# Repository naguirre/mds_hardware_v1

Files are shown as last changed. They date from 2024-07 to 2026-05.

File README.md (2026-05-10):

# mds-hardware

KiCad sources and fabrication outputs for a small network audio player board built around an Allwinner F1C200s SoC, an ESP32-C3 for Wi-Fi, NAND flash storage, an EA3036 power management IC, and an audio DAC daughter board.

The repository contains two KiCad projects:
- [network_player/](network_player/) — the main board
- [dac/](dac/) — the audio DAC daughter board

## Versions

| Version | Date | Status | Schematic | PCB | Gerbers |
|---|---|---|---|-----|---|
| v1 | 2024-01-15 | Sent to JLCPCB, had routing issues | [PDF](docs/v1/schematic.pdf) | [PDF](docs/v1/pcb.pdf) | [ZIP](docs/v1/gerbers.zip) |
| v1.1 | 2024-06-02 | Sent to JLCPCB, fixes routing issues of v1 | [PDF](docs/v1.1/schematic.pdf) | [PDF](docs/v1.1/pcb.pdf) | [ZIP](docs/v1.1/gerbers.zip) |
| v2 | 2024-10-17 | Full redesign on Allwinner T113-s3, never produced | [PDF](docs/v2/schematic.pdf) | [PDF](docs/v2/pcb.pdf) | [ZIP](docs/v2/gerbers.zip) |

References on GitHub: v1 is at commit [`c1560a5`](../../commit/c1560a5), v1.1 is the [`v1.1`](../../tree/v1.1) tag, v2 lives on the [`network_player_v2`](../../tree/network_player_v2) branch. The [`v1_jlcpcb`](../../tree/v1_jlcpcb) tag points to the JLCPCB return files for v1.

## Latest produced version: v1.1

v1.1 is the version that was actually fabricated and assembled by JLCPCB. Compared to v1, it brings the following changes (see commit [`47ae173`](../../commit/47ae173)):

- Removed the discrete transistors used for ESP32 boot/reset, driven directly from F1C200s GPIOs instead
- EA3036 enable pin tied to 3.3 V
- Added a RST button that pulls the MISO line to ground to disable booting from flash
- ESP32 moved to SPI1; SPI0 is now shared between the NAND flash and the RPi connector

### Schematic

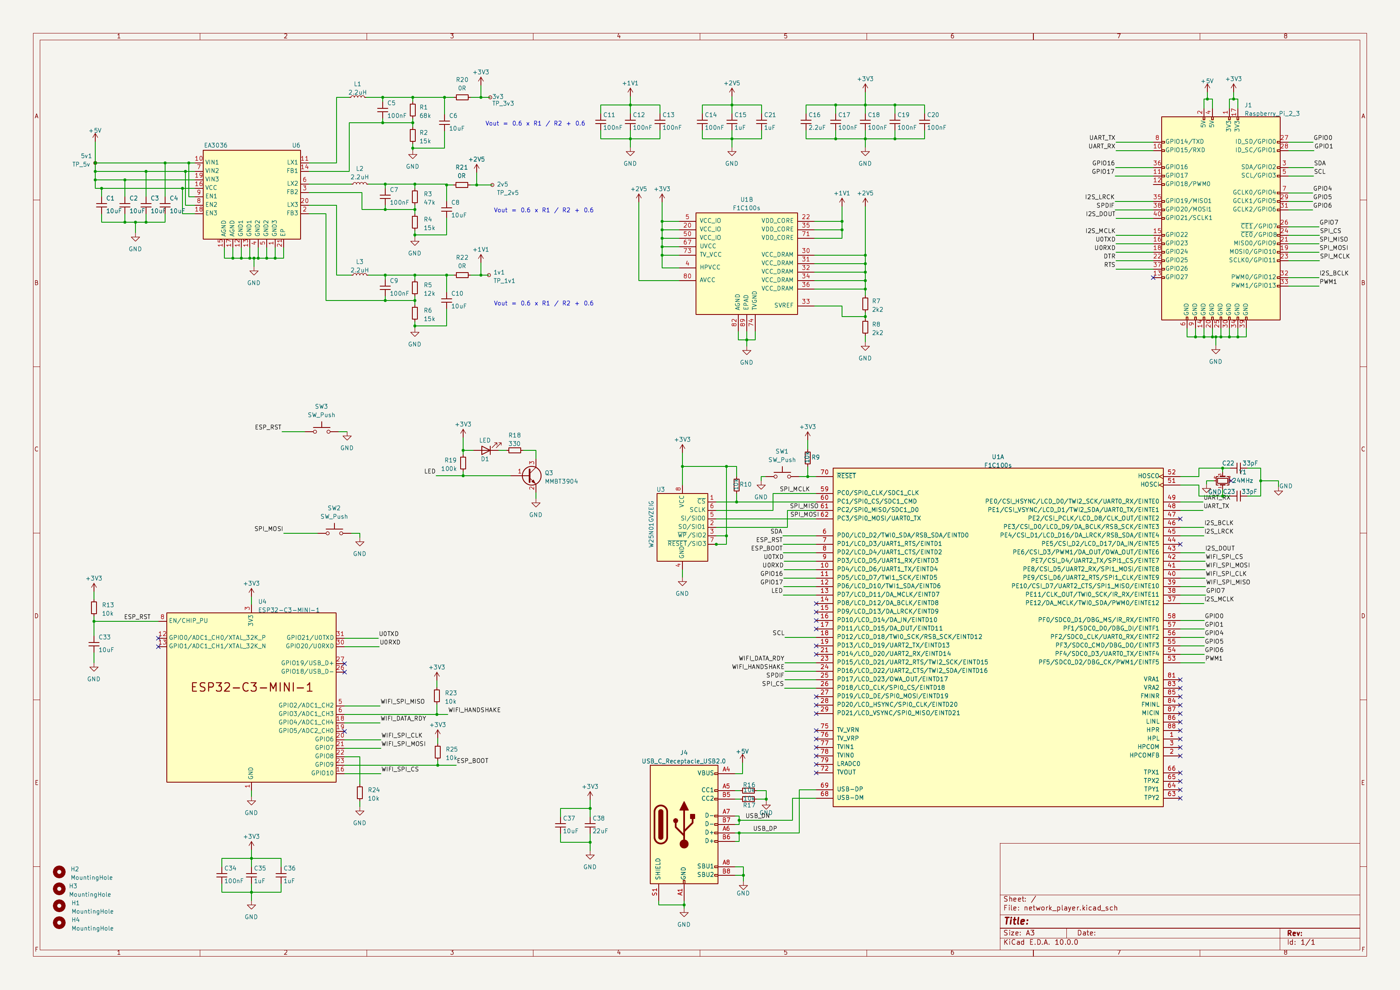
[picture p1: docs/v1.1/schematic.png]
v1.1 schematic


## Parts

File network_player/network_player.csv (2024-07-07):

Comment | Designator | Footprint | LCSC
TP_1v1 | Connector:TestPoint_Small | 1v1
TP_2v5 | Connector:TestPoint_Small | 2v5
TP_3v3 | Connector:TestPoint_Small | 3v3
TP_5v | Connector:TestPoint_Small | 5v1
10uF | Device:C_Small | C1, C2, C3, C4, C6, C8, C10, C33, C37 | C15525
100nF | Device:C_Small | C5, C7, C9, C11, C12, C13, C14, C17, C18, C19, C20, C34 | C307331
1uF | Device:C_Small | C15, C21, C35, C36 | C52923
2.2uF | Device:C_Small | C16 | C12530
33pF | Device:C_Small | C22, C23 | C1562
22uF | Device:C_Small | C38 | C59461
LED | Device:LED | D1 | C2290
MountingHole | Mechanical:MountingHole | H1, H2, H3, H4
Raspberry_Pi_2_3 | Connector:Raspberry_Pi_2_3 | J1
USB_C_Receptacle_USB2.0 | Connector:USB_C_Receptacle_USB2.0 | J4 | C963370
2.2uH | Device:L_Small | L1, L2, L3 | C1043
MMBT3904 | Transistor_BJT:MMBT3904 | Q3 | C20526
68k | Device:R_Small | R1 | C36871
15k | Device:R_Small | R2, R4, R6 | C25756
47k | Device:R_Small | R3 | C25792
12k | Device:R_Small | R5 | C25752
2k2 | Device:R_Small | R7, R8 | C25879
10k | Device:R_Small | R9, R10, R13, R16, R17, R23, R24, R25 | C25744
330 | Device:R_Small | R18 | C25104
100k | Device:R_Small | R19 | C25741
0R | Device:R_Small | R20, R21, R22 | C17168
SW_Push | Switch:SW_Push | SW1, SW2, SW3 | C318884
F1C100s | f1c100s:F1C100s | U1 | C2879851
W25N01GVZEIG | Memory_Flash:MX25R3235FZNxx0 | U3 | C88868
ESP32-C3-MINI-1 | Espressif:ESP32-C3-MINI-1 | U4 | C2838502
EA3036 | EA3036:EA3036 | U6 | C570857
24MHz | Device:Crystal_GND24_Small | Y1 | C15643

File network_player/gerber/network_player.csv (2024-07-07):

Comment | Designator | Footprint | LCSC
TP_1v1 | 1v1 | TestPoint:TestPoint_Pad_D1.0mm
TP_2v5 | 2v5 | TestPoint:TestPoint_Pad_D1.0mm
TP_3v3 | 3v3 | TestPoint:TestPoint_Pad_D1.0mm
TP_5v | 5v1 | TestPoint:TestPoint_Pad_D1.0mm
10uF | C1,C2,C3,C4,C6,C8,C10,C33,C37 | Capacitor_SMD:C_0402_1005Metric | C15525
1uF | C15,C21,C35,C36 | Capacitor_SMD:C_0402_1005Metric | C52923
2.2uF | C16 | Capacitor_SMD:C_0402_1005Metric | C12530
33pF | C22,C23 | Capacitor_SMD:C_0402_1005Metric | C1562
22uF | C38 | Capacitor_SMD:C_0805_2012Metric | C59461
100nF | C5,C7,C9,C11,C12,C13,C14,C17,C18,C19,C20,C34 | Capacitor_SMD:C_0402_1005Metric | C307331
LED | D1 | LED_SMD:LED_0603_1608Metric
MountingHole | H1,H2,H3,H4 | MountingHole:MountingHole_2.7mm_M2.5
Raspberry_Pi_2_3 | J1 | Connector_PinHeader_2.54mm:PinHeader_2x20_P2.54mm_Vertical
USB_C_Receptacle_USB2.0 | J4 | Connector_USB:USB_C_Receptacle_GT-USB-7010 | C963370
2.2uH | L1,L2,L3 | Inductor_SMD:L_0805_2012Metric | C1043
BC817 | Q1,Q2 | Package_TO_SOT_SMD:SOT-23 | C2150
MMBT3904 | Q3 | Package_TO_SOT_SMD:SOT-23 | C20526
68k | R1 | Resistor_SMD:R_0402_1005Metric | C36871
0R | R11,R12,R20,R21,R22 | Resistor_SMD:R_0402_1005Metric | C17168
330 | R18 | Resistor_SMD:R_0402_1005Metric | C25104
100k | R19 | Resistor_SMD:R_0402_1005Metric | C25741
15k | R2,R4,R6 | Resistor_SMD:R_0402_1005Metric | C25756
47k | R3 | Resistor_SMD:R_0402_1005Metric | C25792
12k | R5 | Resistor_SMD:R_0402_1005Metric | C25752
2k2 | R7,R8 | Resistor_SMD:R_0402_1005Metric | C25879
10k | R9,R10,R13,R14,R15,R16,R17 | Resistor_SMD:R_0402_1005Metric | C25744
SW_Push | SW1,SW2,SW3 | Button_Switch_SMD:SW_Push_1P1T_XKB_TS-1187A | C318884
F1C100s | U1 | Package_DFN_QFN:QFN-88_EP_10x10_Pitch0.4mm | C2879851
W25N01GVZEIG | U3 | Package_SON:WSON-8-1EP_8x6mm_P1.27mm_EP3.4x4.3mm | C88868
ESP32-C3-MINI-1 | U4 | espressif:ESP32-C3-MINI-1 | C2838502
EA3036 | U6 | Package_DFN_QFN:QFN-20-1EP_3x3mm_P0.4mm_EP1.65x1.65mm | C570857
24MHz | Y1 | Crystal:Crystal_SMD_SeikoEpson_TSX3225-4Pin_3.2x2.5mm | C15643

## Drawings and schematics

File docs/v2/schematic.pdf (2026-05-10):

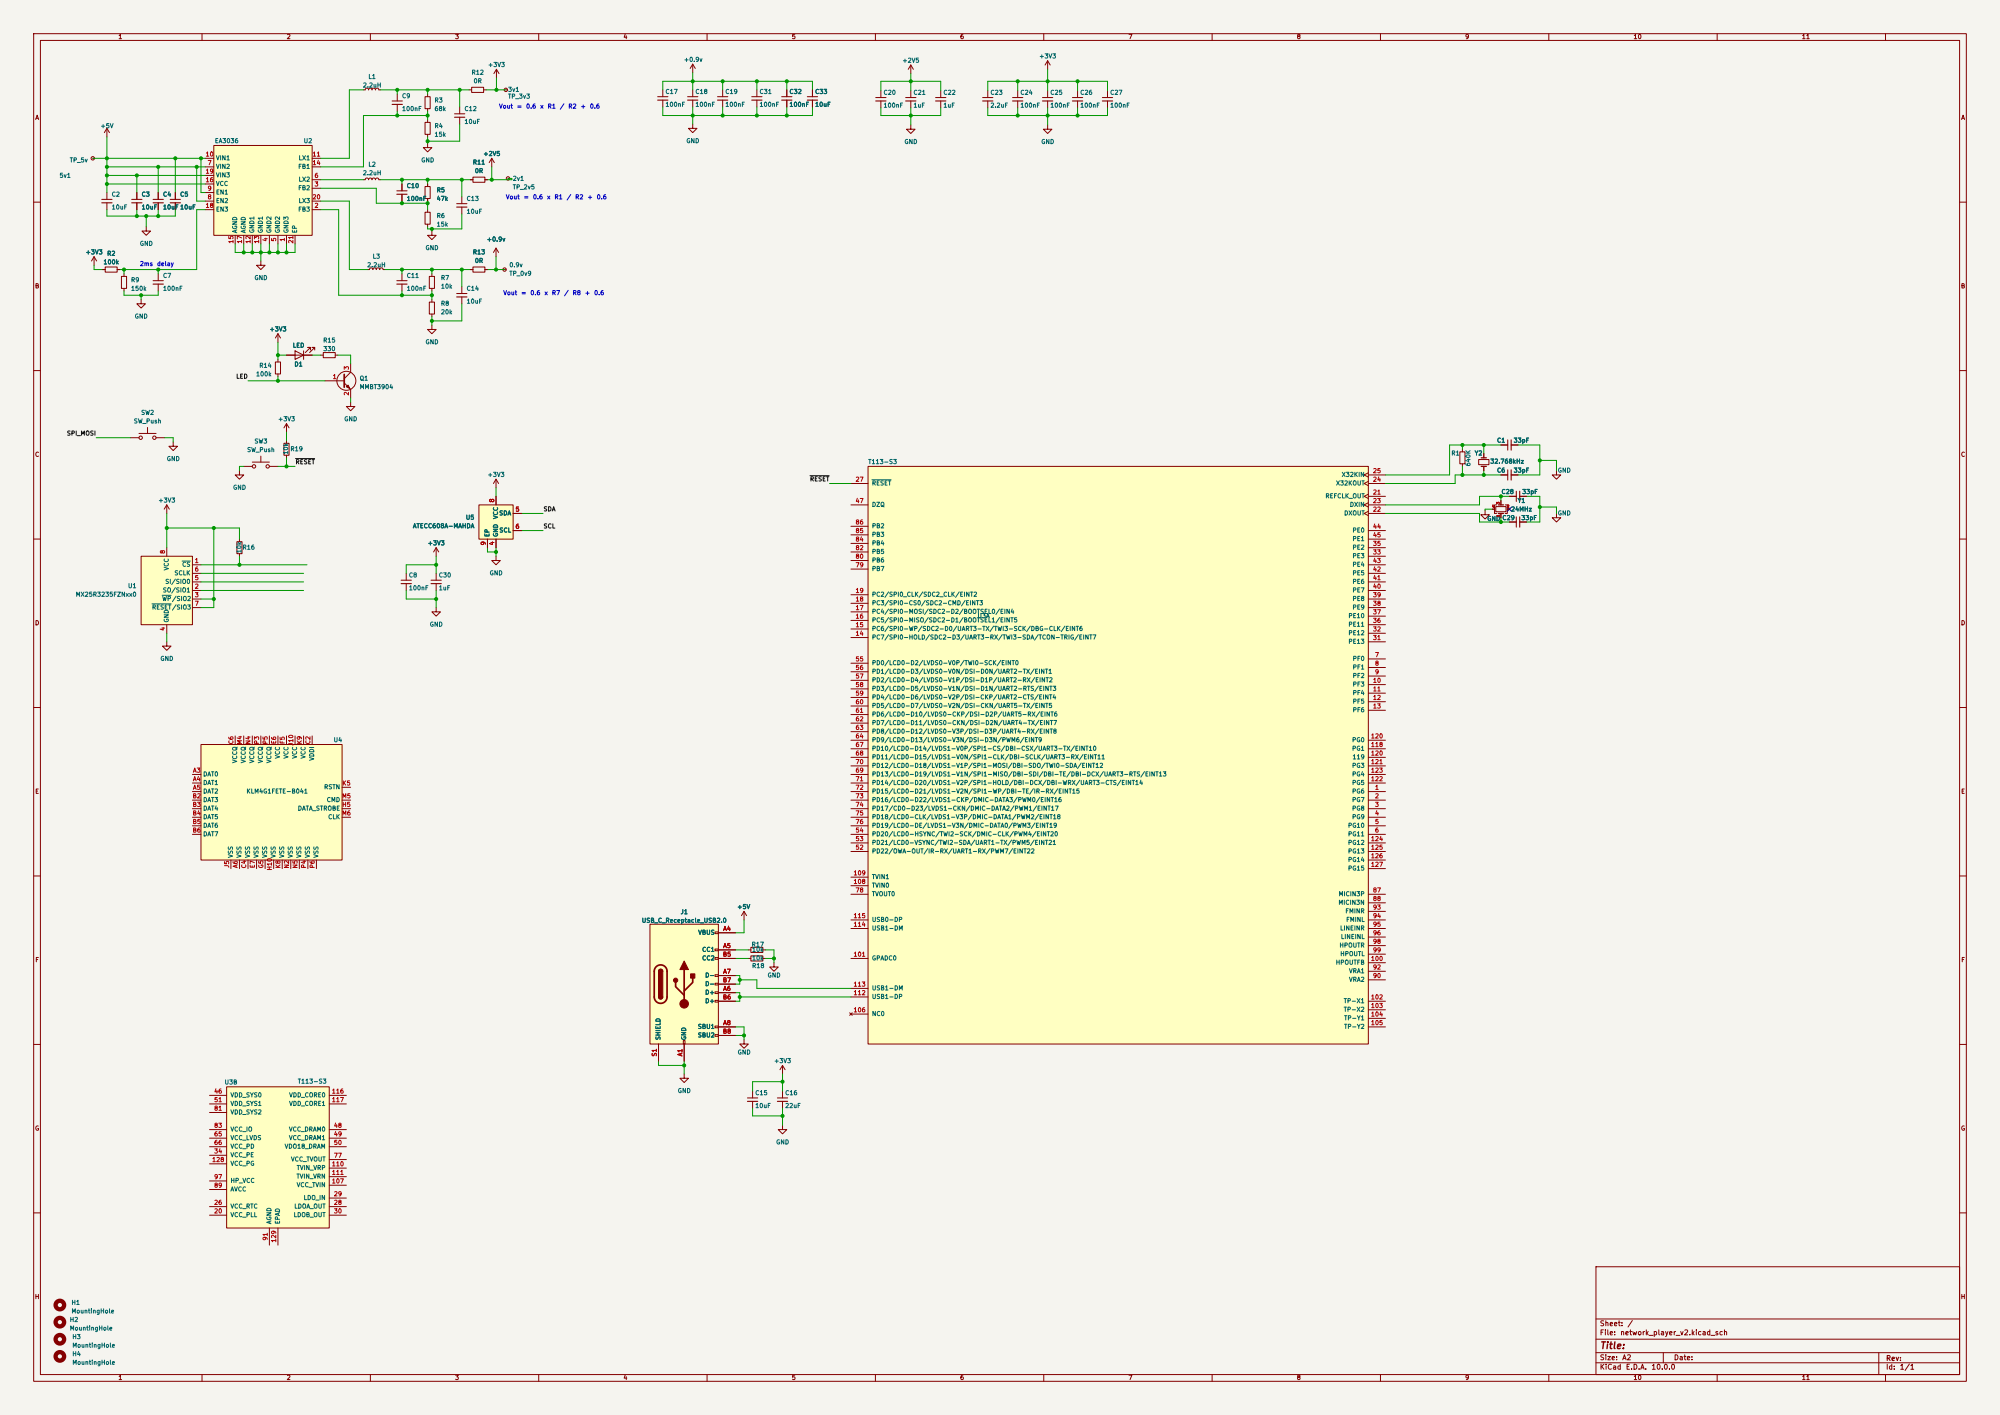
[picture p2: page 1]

Size: A2 | Rev:
KiCad E.D.A. 10.0.0 | Id: 1/1

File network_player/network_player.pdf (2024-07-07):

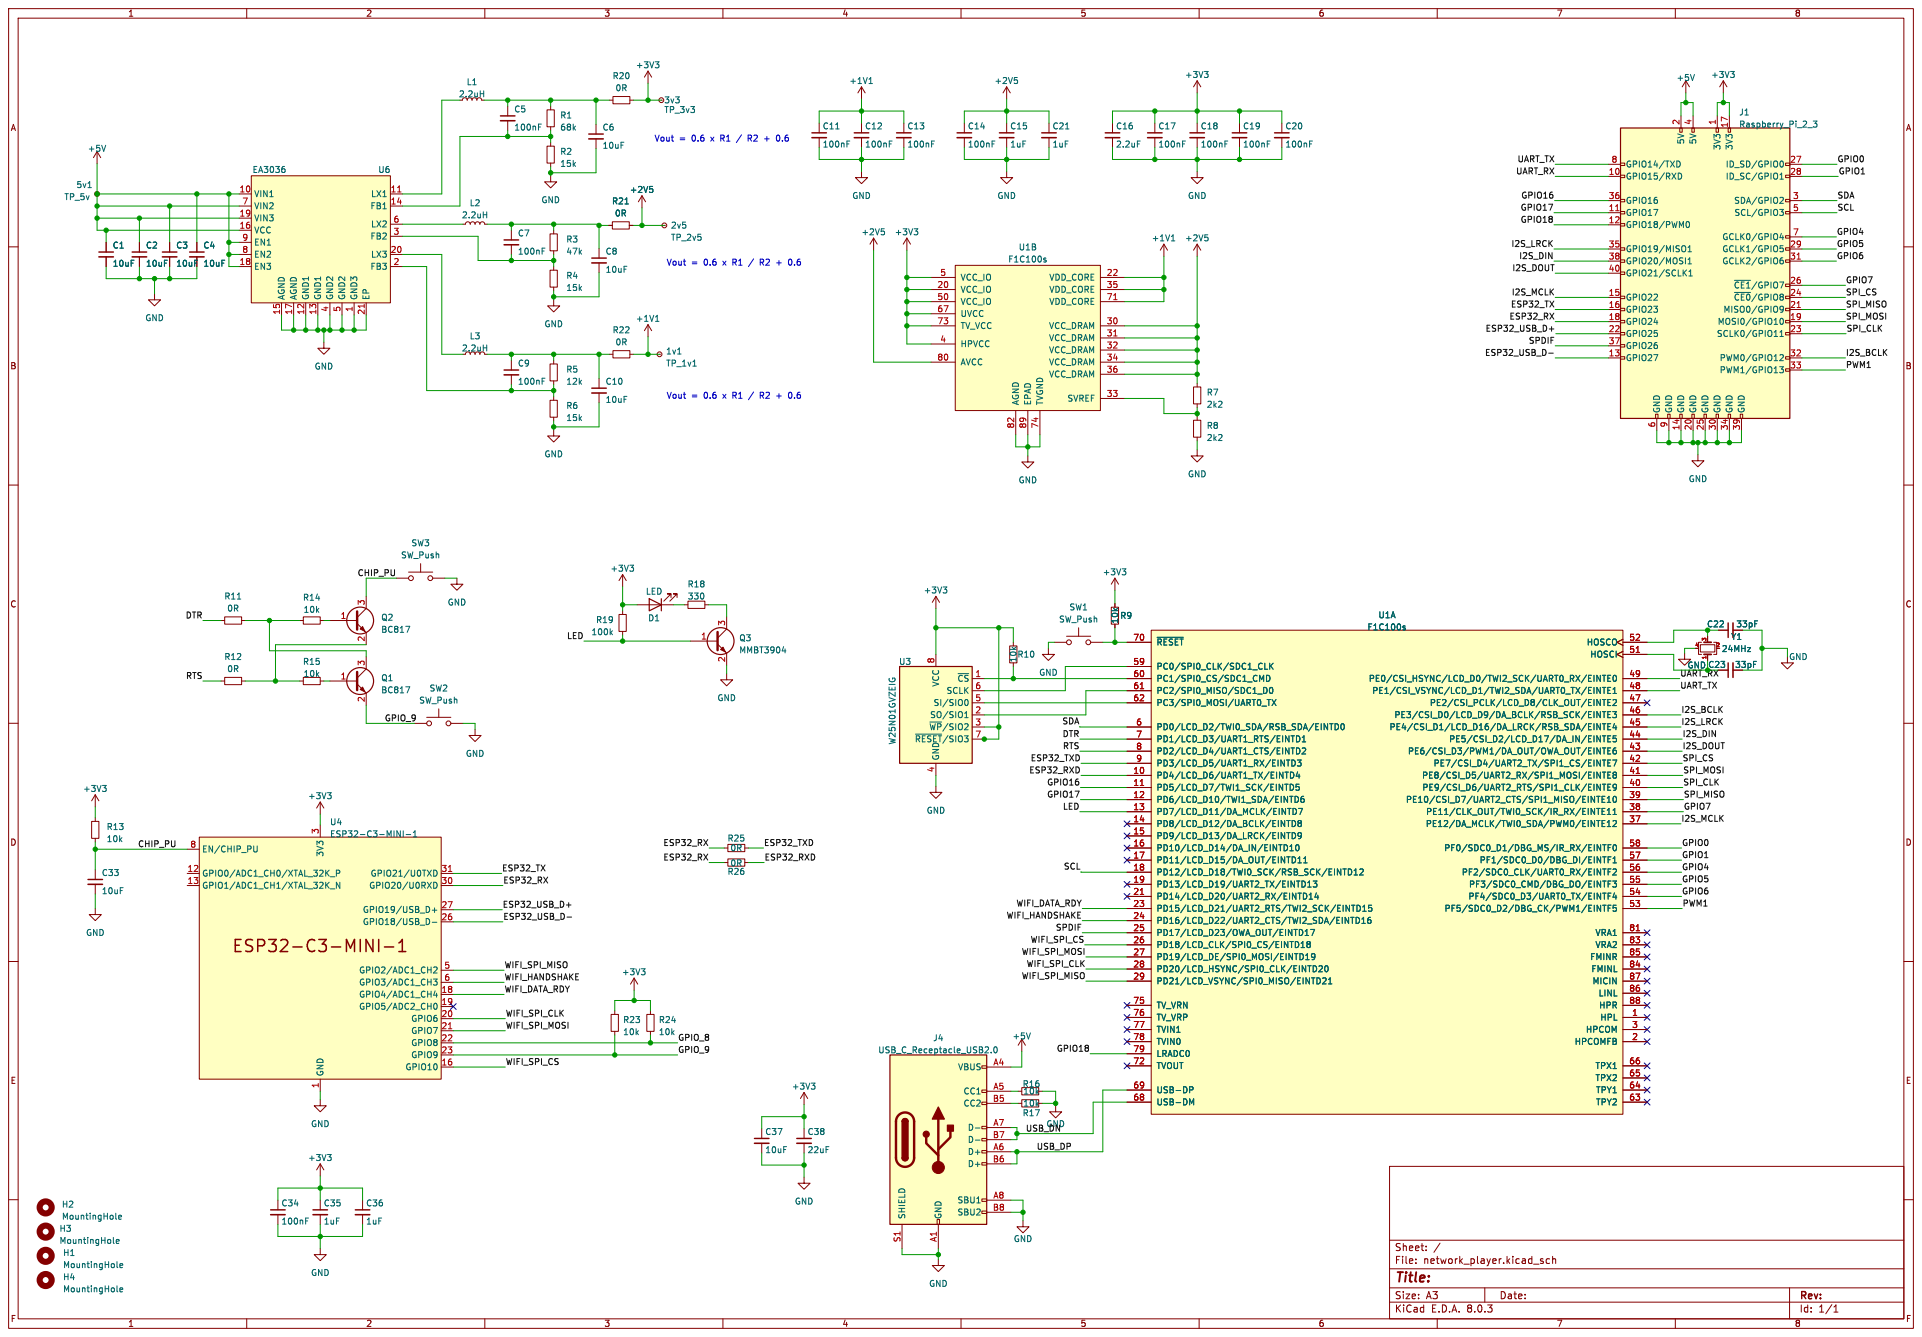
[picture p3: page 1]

4 SI/SIO0 5 SCLK 6 ~{RESET}/SIO37 VCC
~{CS}1 SO/SIO1 2 ~{WP}/SIO23 GND

3 GPIO20/U0RXD 30 GPIO21/U0TXD 31 GPIO2/ADC1_CH2 5 GPIO3/ADC1_CH3 6 EN/CHIP_PU 8 U4ESP32-C3-MINI-1 GND GND

Id: 1/1 Title: File: network_player.kicad_sch Sheet: /

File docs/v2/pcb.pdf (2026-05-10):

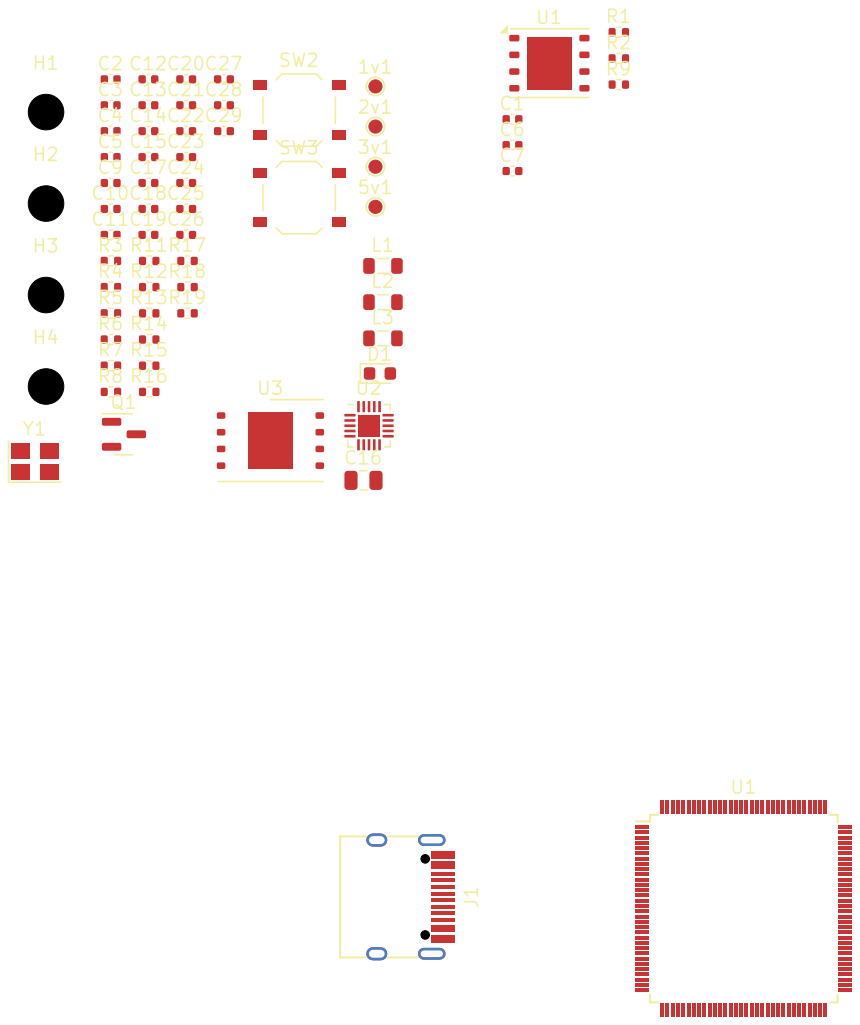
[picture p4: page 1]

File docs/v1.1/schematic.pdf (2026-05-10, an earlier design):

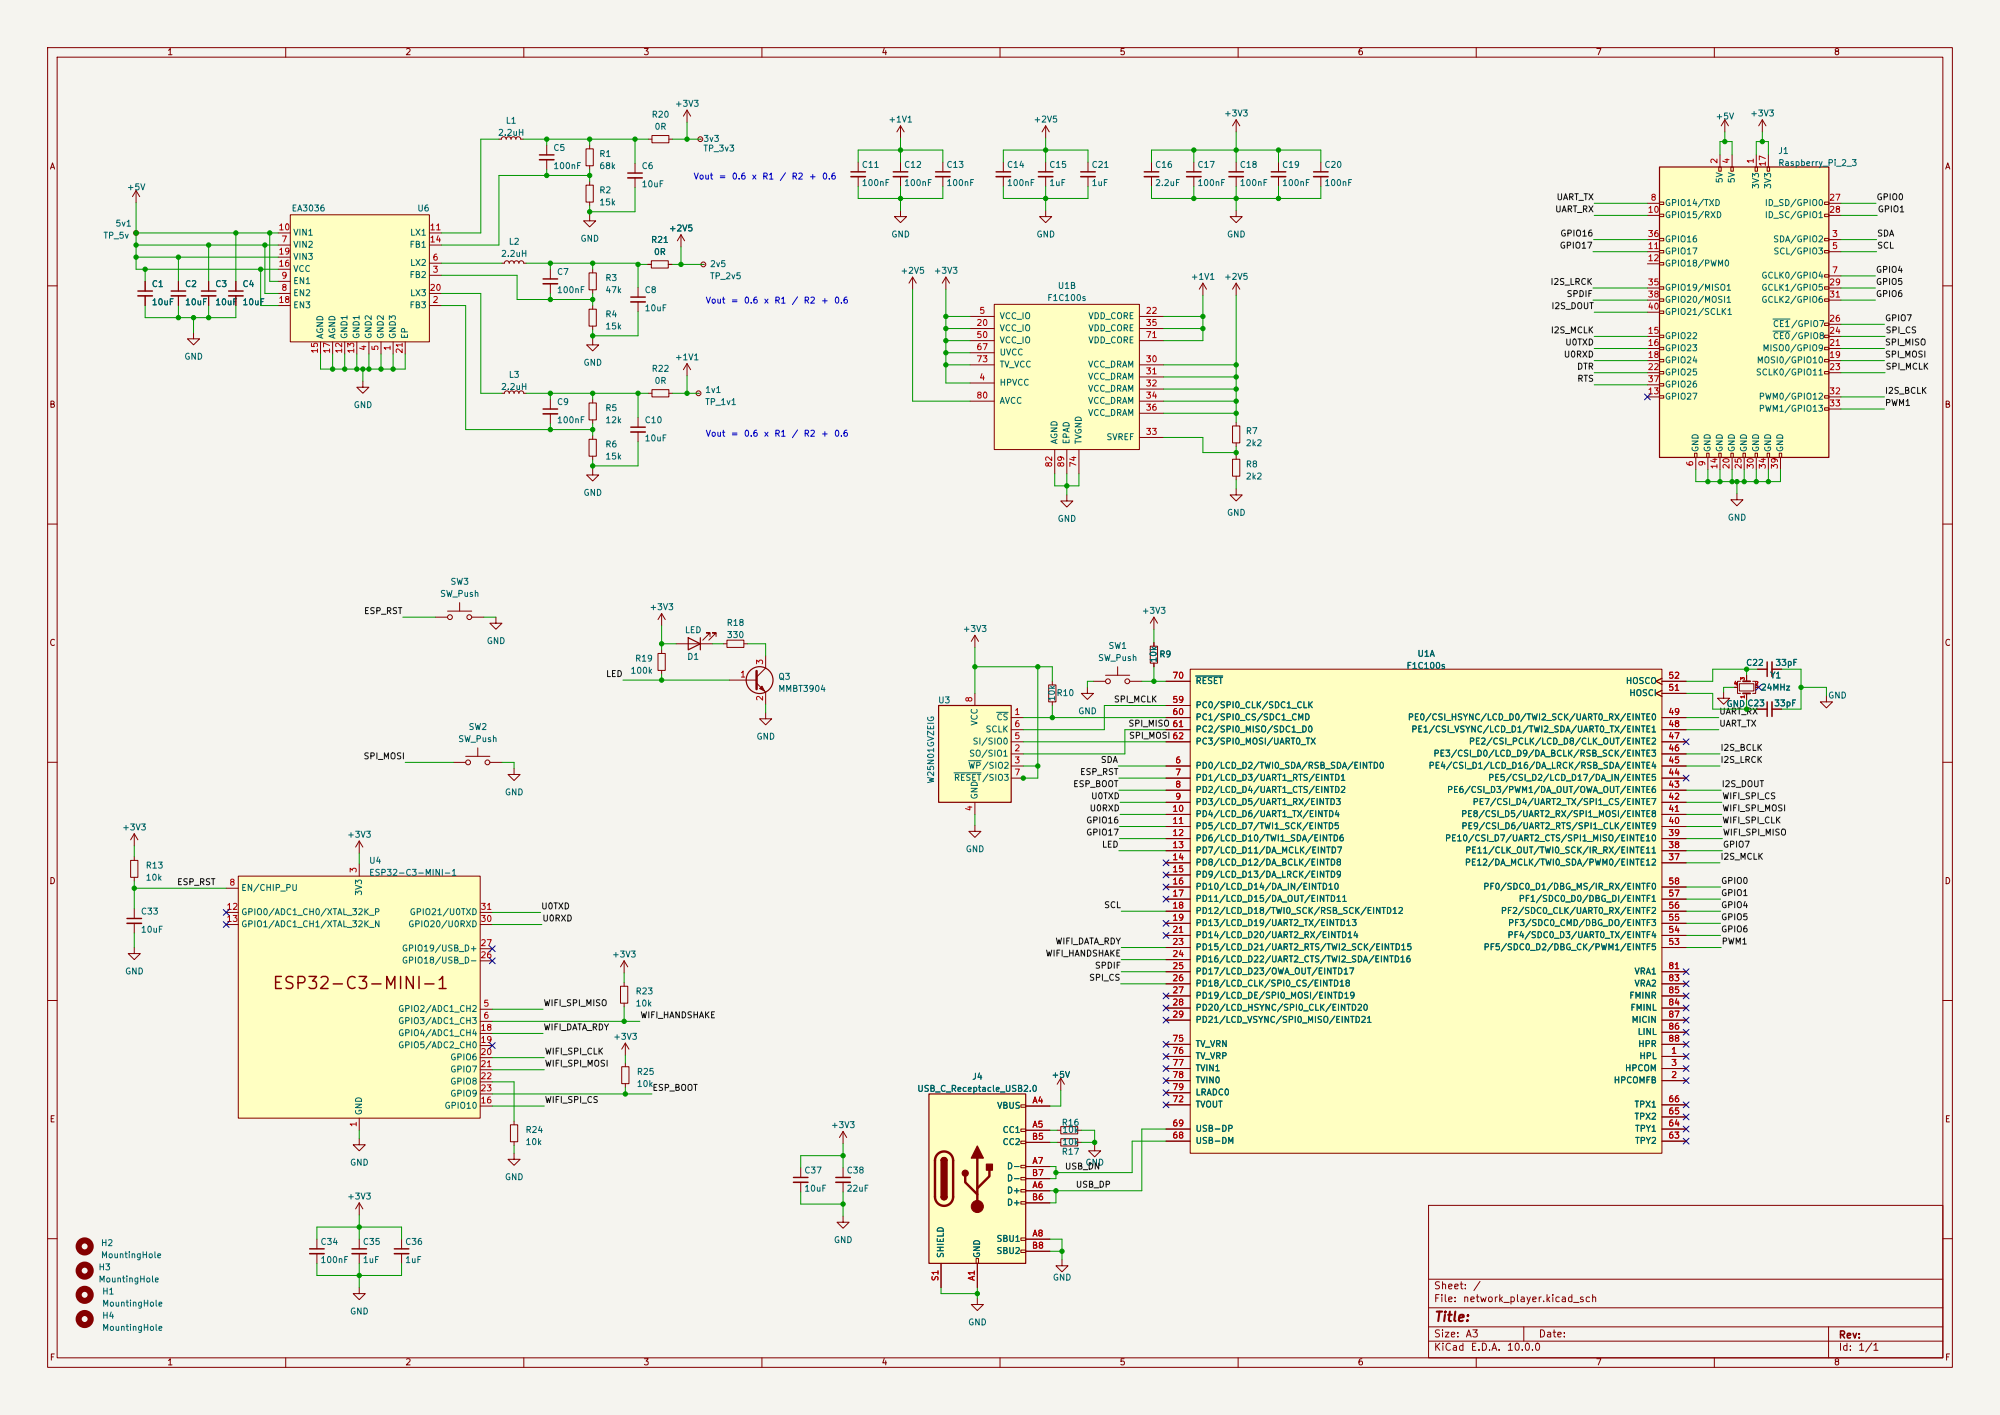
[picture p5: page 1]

VIN2 7
VIN3 19

Size: A3 | Rev: | F Date:
KiCad E.D.A. 10.0.0 | Id: 1/1

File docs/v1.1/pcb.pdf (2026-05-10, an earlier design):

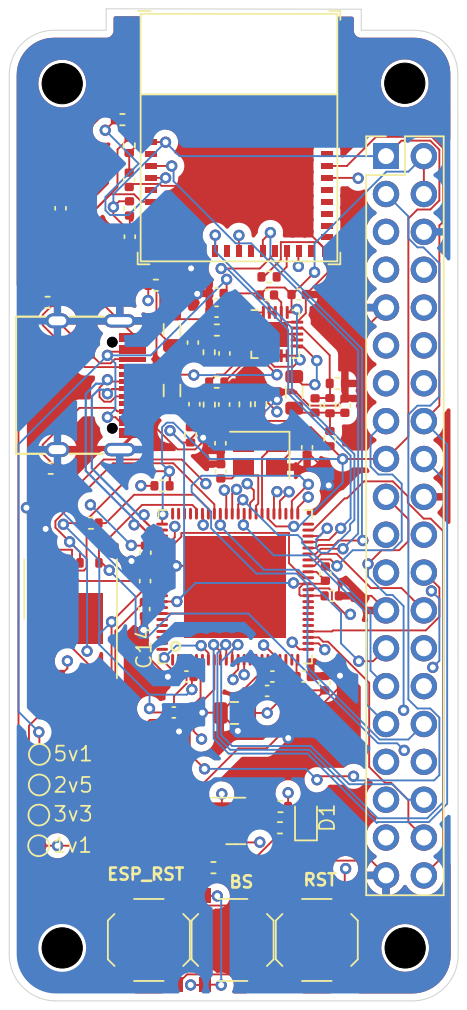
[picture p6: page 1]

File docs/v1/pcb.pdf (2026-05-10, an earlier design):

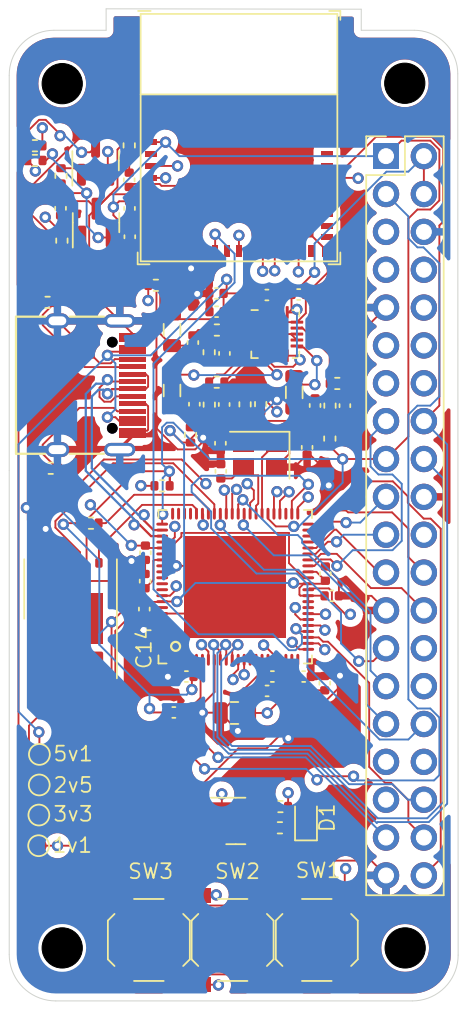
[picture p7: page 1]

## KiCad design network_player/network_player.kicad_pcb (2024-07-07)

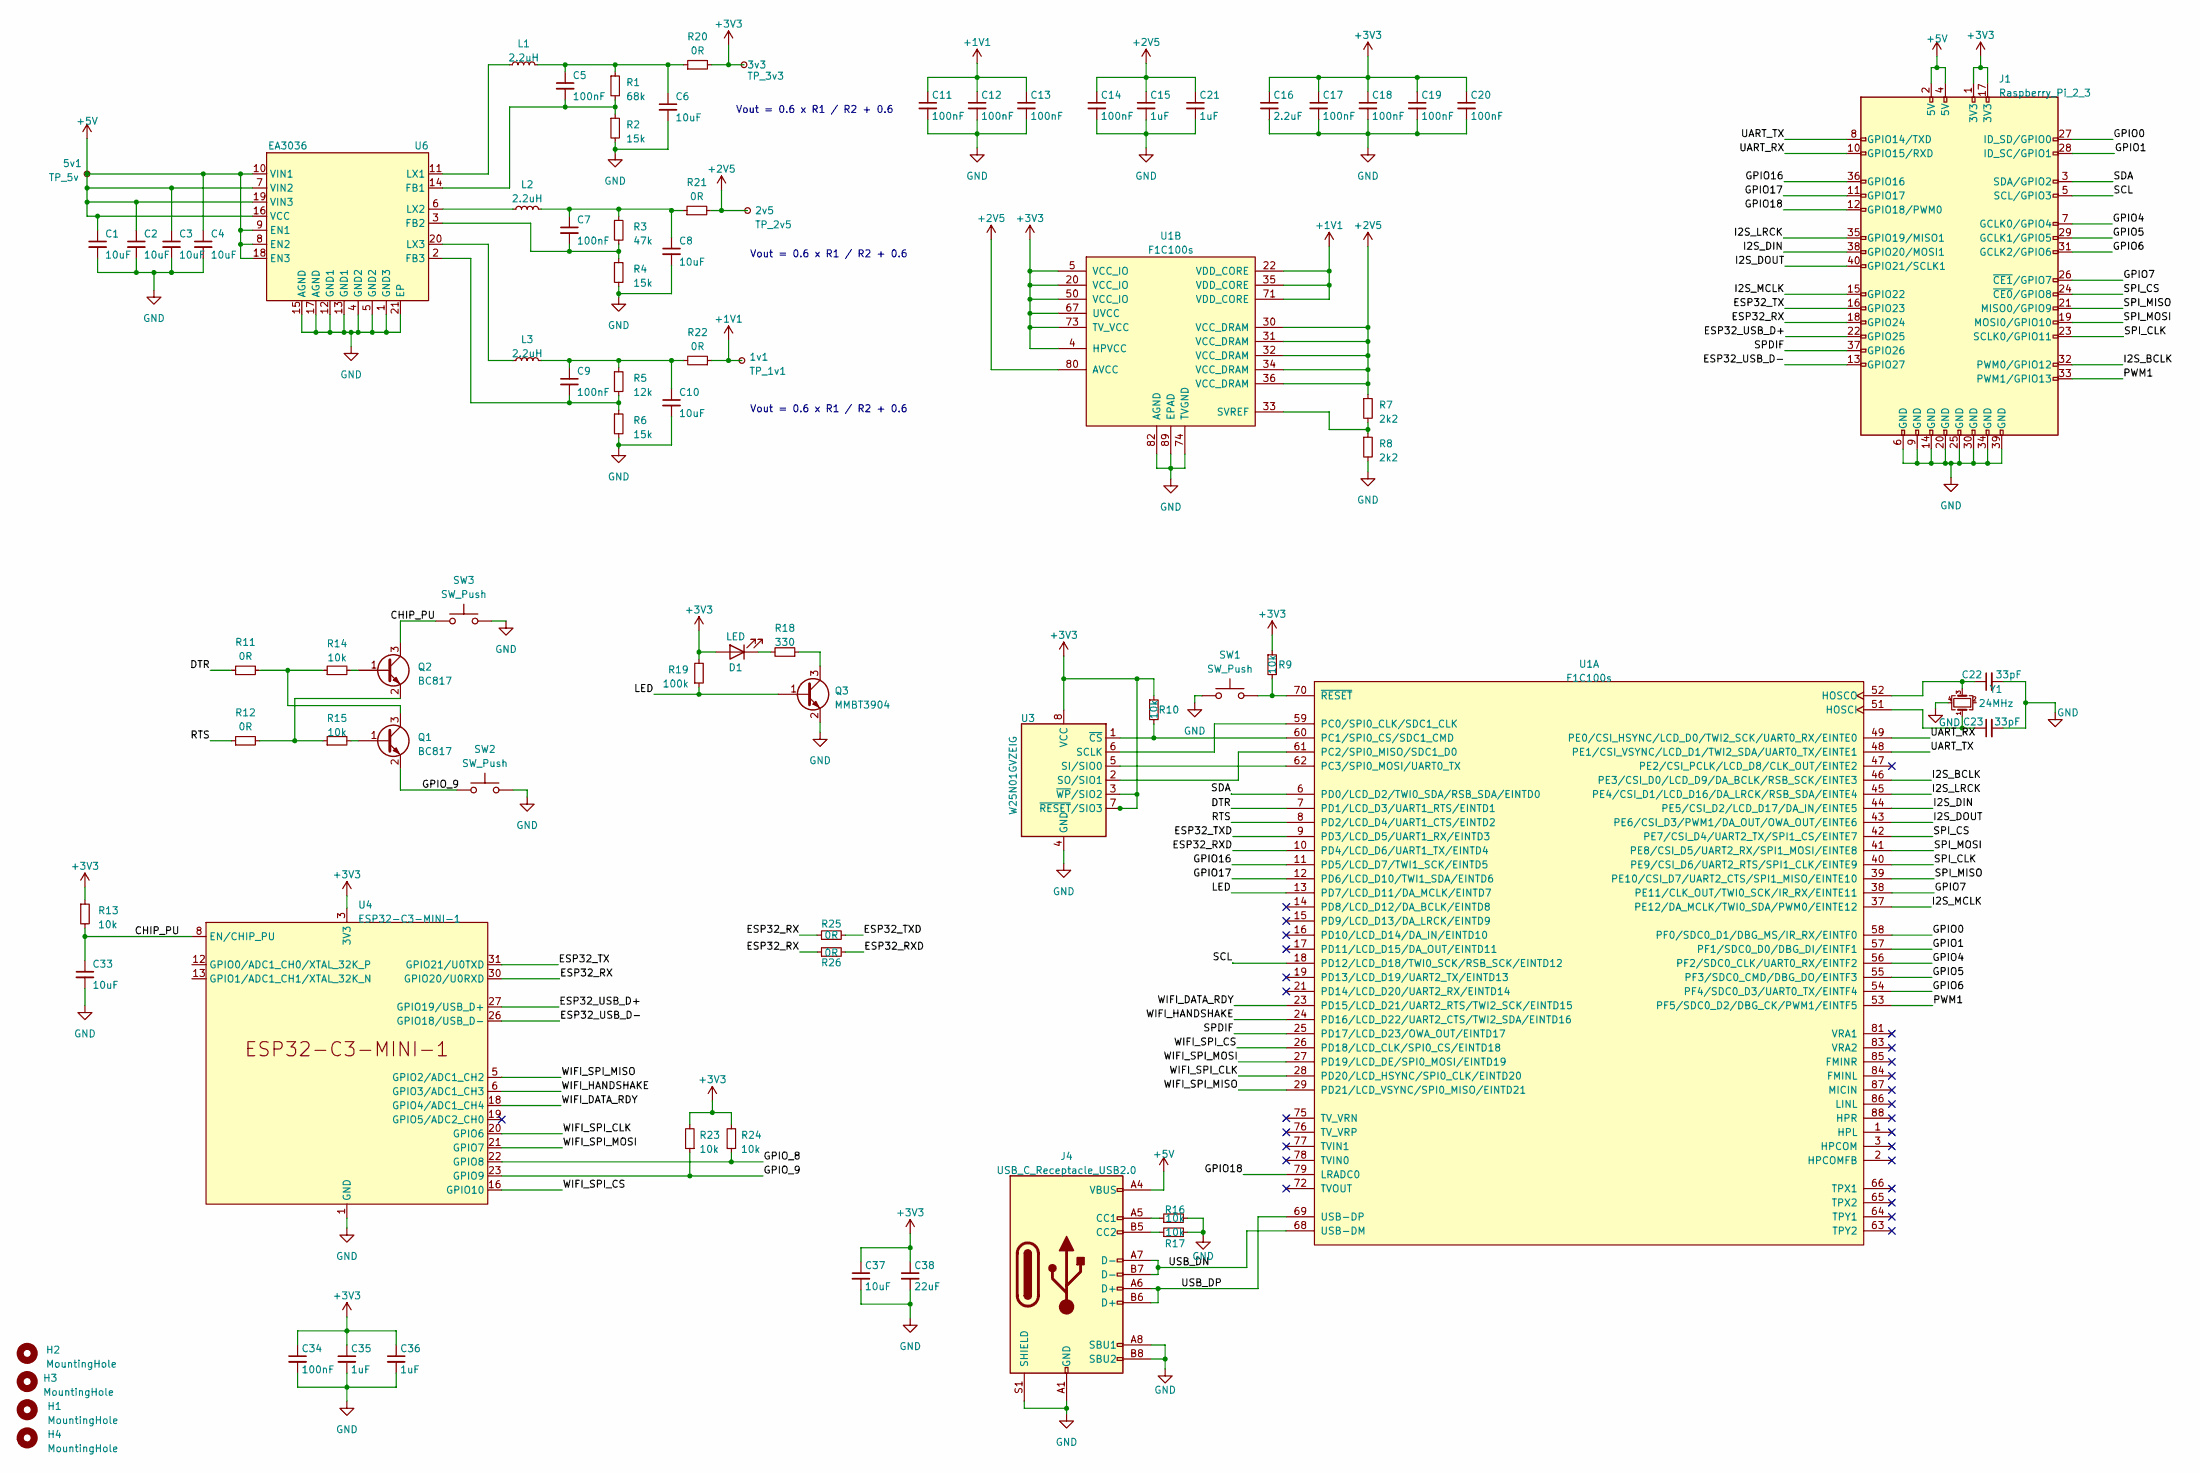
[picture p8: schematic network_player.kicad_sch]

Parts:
1v1: TP_1v1; TestPoint_Pad_D1.0mm
2v5: TP_2v5; TestPoint_Pad_D1.0mm
3v3: TP_3v3; TestPoint_Pad_D1.0mm
5v1: TP_5v; TestPoint_Pad_D1.0mm
C1, C2, C3, C4, C6, C8, C10, C33, C37: 10uF; C_0402_1005Metric; LCSC C15525
C5, C7, C9, C11, C12, C13, C14, C17, C18, C19, C20, C34: 100nF; C_0402_1005Metric; LCSC C307331
C15, C21, C35, C36: 1uF; C_0402_1005Metric; LCSC C52923
C16: 2.2uF; C_0402_1005Metric; LCSC C12530
C22, C23: 33pF; C_0402_1005Metric; LCSC C1562
C38: 22uF; C_0805_2012Metric; LCSC C59461
D1: LED; LED_0603_1608Metric
H1, H2, H3, H4: MountingHole; MountingHole_2.7mm_M2.5
J1: Raspberry_Pi_2_3; PinHeader_2x20_P2.54mm_Vertical
J4: USB_C_Receptacle_USB2.0; USB_C_Receptacle_GT-USB-7010; LCSC C963370
L1, L2, L3: 2.2uH; L_0805_2012Metric; LCSC C1043
Q1, Q2: BC817; SOT-23; LCSC C2150
Q3: MMBT3904; SOT-23; LCSC C20526
R1: 68k; R_0402_1005Metric; LCSC C36871
R2, R4, R6: 15k; R_0402_1005Metric; LCSC C25756
R3: 47k; R_0402_1005Metric; LCSC C25792
R5: 12k; R_0402_1005Metric; LCSC C25752
R7, R8: 2k2; R_0402_1005Metric; LCSC C25879
R9, R10, R13, R14, R15, R16, R17, R23, R24: 10k; R_0402_1005Metric; LCSC C25744
R11, R12, R20, R21, R22, R25, R26: 0R; R_0402_1005Metric; LCSC C17168
R18: 330; R_0402_1005Metric; LCSC C25104
R19: 100k; R_0402_1005Metric; LCSC C25741
SW1, SW2, SW3: SW_Push; SW_Push_1P1T_XKB_TS-1187A; LCSC C318884
U1: F1C100s; QFN-88_EP_10x10_Pitch0.4mm; LCSC C2879851
U3: W25N01GVZEIG; WSON-8-1EP_8x6mm_P1.27mm_EP3.4x4.3mm; LCSC C88868
U4: ESP32-C3-MINI-1; LCSC C2838502
U6: EA3036; QFN-20-1EP_3x3mm_P0.4mm_EP1.65x1.65mm; LCSC C570857
Y1: 24MHz; Crystal_SMD_SeikoEpson_TSX3225-4Pin_3.2x2.5mm; LCSC C15643

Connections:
+1V1: 1v1.1, C11.1, C12.1, C13.1, R22.1, U1.22 (VDD_CORE), U1.35 (VDD_CORE), U1.71 (VDD_CORE)
+2V5: 2v5.1, C14.1, C15.1, C21.1, R7.1, R21.2, U1.30 (VCC_DRAM), U1.31 (VCC_DRAM), U1.32 (VCC_DRAM), U1.34 (VCC_DRAM), U1.36 (VCC_DRAM), U1.80 (AVCC)
+3V3: 3v3.1, C16.1, C17.1, C18.1, C19.1, C20.1, C34.1, C35.1, C36.1, C37.1, C38.1, D1.2 (A), J1.1 (3V3), J1.17 (3V3), R9.1, R10.1, R13.1, R19.2, R20.2, R23.2, R24.2, U1.4 (HPVCC), U1.5 (VCC_IO), U1.20 (VCC_IO), U1.50 (VCC_IO), U1.67 (UVCC), U1.73 (TV_VCC), U3.3 (~WP/SIO2), U3.7 (~RESET/SIO3), U3.8 (VCC), U4.3 (3V3)
+5V: 5v1.1, C1.1, C2.1, C3.1, C4.1, J1.2 (5V), J1.4 (5V), J4.A4 (VBUS), J4.A9 (VBUS), J4.B4 (VBUS), J4.B9 (VBUS), U6.7 (VIN2), U6.8 (EN2), U6.9 (EN1), U6.10 (VIN1), U6.16 (VCC), U6.18 (EN3), U6.19 (VIN3)
/CHIP_PU: C33.1, Q2.3 (C), R13.2, SW3.1, U4.8 (EN/CHIP_PU)
/DTR: R11.1, U1.7 (PD1/LCD_D3/UART1_RTS/EINTD1)
/ESP32_RX: J1.18 (GPIO24), R25.1, R26.1, U4.30 (GPIO20/U0RXD)
/ESP32_RXD: R26.2, U1.10 (PD4/LCD_D6/UART1_TX/EINTD4)
/ESP32_TX: J1.16 (GPIO23), U4.31 (GPIO21/U0TXD)
/ESP32_TXD: R25.2, U1.9 (PD3/LCD_D5/UART1_RX/EINTD3)
/ESP32_USB_D+: J1.22 (GPIO25), U4.27 (GPIO19/USB_D+)
/ESP32_USB_D-: J1.13 (GPIO27), U4.26 (GPIO18/USB_D-)
/GPIO0: J1.27 (ID_SD/GPIO0), U1.58 (PF0/SDC0_D1/DBG_MS/IR_RX/EINTF0)
/GPIO1: J1.28 (ID_SC/GPIO1), U1.57 (PF1/SDC0_D0/DBG_DI/EINTF1)
/GPIO4: J1.7 (GCLK0/GPIO4), U1.56 (PF2/SDC0_CLK/UART0_RX/EINTF2)
/GPIO5: J1.29 (GCLK1/GPIO5), U1.55 (PF3/SDC0_CMD/DBG_DO/EINTF3)
/GPIO6: J1.31 (GCLK2/GPIO6), U1.54 (PF4/SDC0_D3/UART0_TX/EINTF4)
/GPIO7: J1.26 (~CE1/GPIO7), U1.38 (PE11/CLK_OUT/TWI0_SCK/IR_RX/EINTE11)
/GPIO16: J1.36 (GPIO16), U1.11 (PD5/LCD_D7/TWI1_SCK/EINTD5)
/GPIO17: J1.11 (GPIO17), U1.12 (PD6/LCD_D10/TWI1_SDA/EINTD6)
/GPIO18: J1.12 (GPIO18/PWM0), U1.79 (LRADC0)
/GPIO_8: R24.1, U4.22 (GPIO8)
/GPIO_9: Q1.2 (E), R23.1, SW2.1, U4.23 (GPIO9)
/I2S_BCLK: J1.32 (PWM0/GPIO12), U1.46 (PE3/CSI_D0/LCD_D9/DA_BCLK/RSB_SCK/EINTE3)
/I2S_DIN: J1.38 (GPIO20/MOSI1), U1.44 (PE5/CSI_D2/LCD_D17/DA_IN/EINTE5)
/I2S_DOUT: J1.40 (GPIO21/SCLK1), U1.43 (PE6/CSI_D3/PWM1/DA_OUT/OWA_OUT/EINTE6)
/I2S_LRCK: J1.35 (GPIO19/MISO1), U1.45 (PE4/CSI_D1/LCD_D16/DA_LRCK/RSB_SDA/EINT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)
/I2S_MCLK: J1.15 (GPIO22), U1.37 (PE12/DA_MCLK/TWI0_SDA/PWM0/EINTE12)
/LED: Q3.1 (B), R19.1, U1.13 (PD7/LCD_D11/DA_MCLK/EINTD7)
/PWM1: J1.33 (PWM1/GPIO13), U1.53 (PF5/SDC0_D2/DBG_CK/PWM1/EINTF5)
/RTS: R12.1, U1.8 (PD2/LCD_D4/UART1_CTS/EINTD2)
/SCL: J1.5 (SCL/GPIO3), U1.18 (PD12/LCD_D18/TWI0_SCK/RSB_SCK/EINTD12)
/SDA: J1.3 (SDA/GPIO2), U1.6 (PD0/LCD_D2/TWI0_SDA/RSB_SDA/EINTD0)
/SPDIF: J1.37 (GPIO26), U1.25 (PD17/LCD_D23/OWA_OUT/EINTD17)
/SPI_CLK: J1.23 (SCLK0/GPIO11), U1.40 (PE9/CSI_D6/UART2_RTS/SPI1_CLK/EINTE9)
/SPI_CS: J1.24 (~CE0/GPIO8), U1.42 (PE7/CSI_D4/UART2_TX/SPI1_CS/EINTE7)
/SPI_MISO: J1.21 (MISO0/GPIO9), U1.39 (PE10/CSI_D7/UART2_CTS/SPI1_MISO/EINTE10)
/SPI_MOSI: J1.19 (MOSI0/GPIO10), U1.41 (PE8/CSI_D5/UART2_RX/SPI1_MOSI/EINTE8)
/UART_RX: J1.10 (GPIO15/RXD), U1.49 (PE0/CSI_HSYNC/LCD_D0/TWI2_SCK/UART0_RX/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)
/UART_TX: J1.8 (GPIO14/TXD), U1.48 (PE1/CSI_VSYNC/LCD_D1/TWI2_SDA/UART0_TX/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)
/USB_DN: J4.A7 (D-), J4.B7 (D-), U1.68 (USB-DM)
/USB_DP: J4.A6 (D+), J4.B6 (D+), U1.69 (USB-DP)
/WIFI_DATA_RDY: U1.23 (PD15/LCD_D21/UART2_RTS/TWI2_SCK/EINTD15), U4.18 (GPIO4/ADC1_CH4)
/WIFI_HANDSHAKE: U1.24 (PD16/LCD_D22/UART2_CTS/TWI2_SDA/EINTD16), U4.6 (GPIO3/ADC1_CH3)
/WIFI_SPI_CLK: U1.28 (PD20/LCD_HSYNC/SPI0_CLK/EINTD20), U4.20 (GPIO6)
/WIFI_SPI_CS: U1.26 (PD18/LCD_CLK/SPI0_CS/EINTD18), U4.16 (GPIO10)
/WIFI_SPI_MISO: U1.29 (PD21/LCD_VSYNC/SPI0_MISO/EINTD21), U4.5 (GPIO2/ADC1_CH2)
/WIFI_SPI_MOSI: U1.27 (PD19/LCD_DE/SPI0_MOSI/EINTD19), U4.21 (GPIO7)
GND: C1.2, C2.2, C3.2, C4.2, C6.2, C8.2, C10.2, C11.2, C12.2, C13.2, C14.2, C15.2, C16.2, C17.2, C18.2, C19.2, C20.2, C21.2, C22.2, C23.2, C33.2, C34.2, C35.2, C36.2, C37.2, C38.2, J1.6 (GND), J1.9 (GND), J1.14 (GND), J1.20 (GND), J1.25 (GND), J1.30 (GND), J1.34 (GND), J1.39 (GND), J4.A1 (GND), J4.A8 (SBU1), J4.A12 (GND), J4.B1 (GND), J4.B8 (SBU2), J4.B12 (GND), J4.S1 (SHIELD), Q3.2 (E), R2.2, R4.2, R6.2, R8.2, R16.2, R17.2, SW1.1, SW2.2, SW3.2, U1.74 (TVGND), U1.82 (AGND), U1.89 (EPAD), U3.4 (GND), U3.9 (GND), U4.1 (GND), U4.2 (GND), U4.11 (GND), U4.14 (GND), U4.36 (GND), U4.37 (GND), U4.38 (GND), U4.39 (GND), U4.40 (GND), U4.41 (GND), U4.42 (GND), U4.43 (GND), U4.44 (GND), U4.45 (GND), U4.46 (GND), U4.47 (GND), U4.48 (GND), U4.49 (GND), U4.50 (GND), U4.51 (GND), U4.52 (GND), U4.53 (GND), U6.1 (GND3), U6.4 (GND2), U6.5 (GND2), U6.12 (GND1), U6.13 (GND1), U6.15 (AGND), U6.17 (AGND), U6.21 (EP), Y1.4
unnamed: C5.1, C6.1, L1.2, R1.1, R20.1
unnamed: C7.1, C8.1, L2.2, R3.1, R21.1
unnamed: C9.1, C10.1, L3.2, R5.1, R22.2
unnamed: D1.1 (K), R18.2
unnamed: J4.A5 (CC1), R16.1
unnamed: J4.B5 (CC2), R17.1
unnamed: Q1.1 (B), R15.2
unnamed: Q1.3 (C), R11.2, R14.1
unnamed: Q2.1 (B), R14.2
unnamed: Q2.2 (E), R12.2, R15.1
unnamed: Q3.3 (C), R18.1
unnamed: C23.1, U1.51 (HOSCI), Y1.1
unnamed: C22.1, U1.52 (HOSCO), Y1.3
unnamed: U1.59 (PC0/SPI0_CLK/SDC1_CLK), U3.6 (SCLK)
unnamed: R10.2, U1.60 (PC1/SPI0_CS/SDC1_CMD), U3.1 (~CS)
unnamed: U1.61 (PC2/SPI0_MISO/SDC1_D0), U3.2 (SO/SIO1)
unnamed: U1.62 (PC3/SPI0_MOSI/UART0_TX), U3.5 (SI/SIO0)
unnamed: R9.2, SW1.2, U1.70 (~RESET)
unnamed: R7.2, R8.1, U1.33 (SVREF)
unnamed: C5.2, R1.2, R2.1, U6.14 (FB1)
unnamed: C7.2, R3.2, R4.1, U6.3 (FB2)
unnamed: C9.2, R5.2, R6.1, U6.2 (FB3)
unnamed: L1.1, U6.11 (LX1)
unnamed: L2.1, U6.6 (LX2)
unnamed: L3.1, U6.20 (LX3)

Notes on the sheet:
Vout = 0.6 x R1 / R2 + 0.6

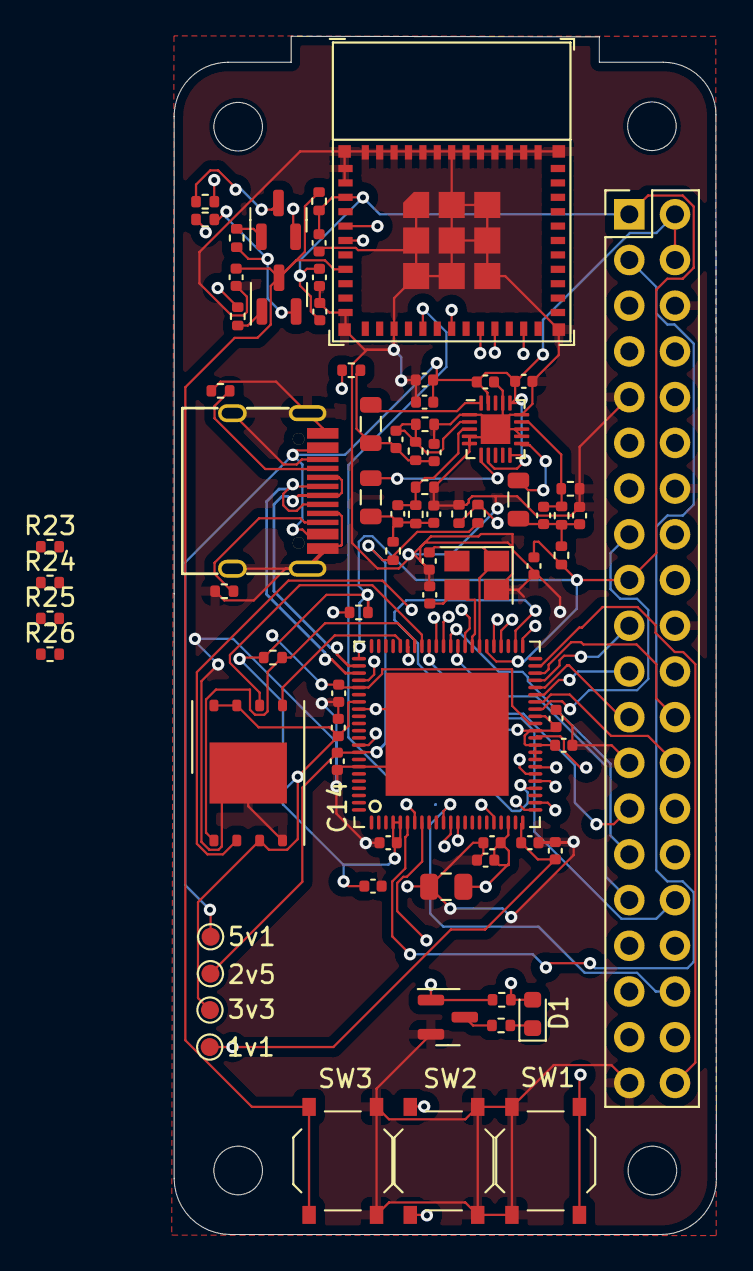
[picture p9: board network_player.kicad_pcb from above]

Board: 4 copper layers, 30.1 x 66.6 mm, 80 parts (0 on the bottom side), 74 nets.

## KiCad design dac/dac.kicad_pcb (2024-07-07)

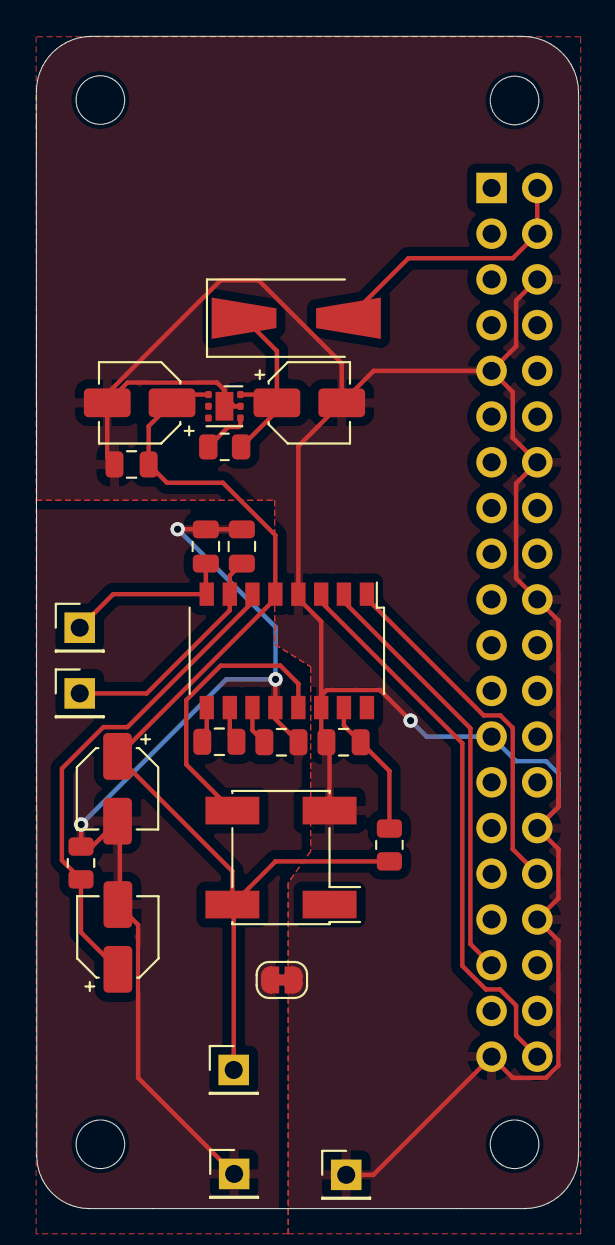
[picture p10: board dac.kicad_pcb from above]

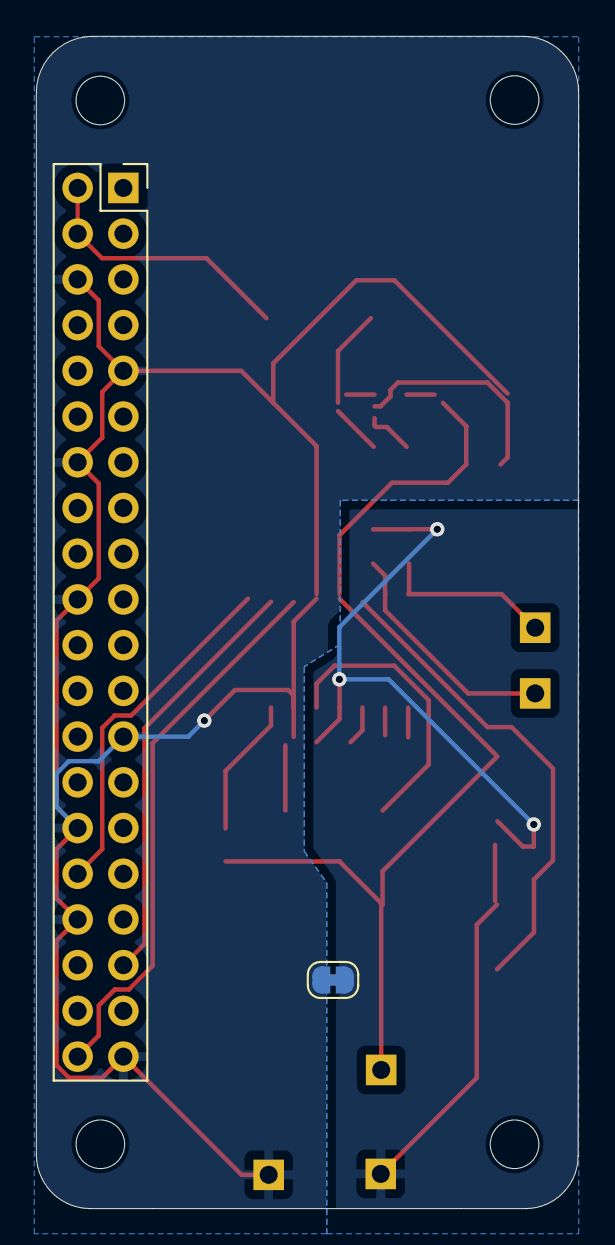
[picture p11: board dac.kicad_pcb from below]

Board: 2 copper layers, 30.1 x 65.1 mm, 29 parts (2 on the bottom side), 17 nets.

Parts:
C1: 2.2uF; C_0805_2012Metric
C2: 2.2uF/50V; CP_Elec_4x5.8
C3, C8, C9: 10uF/25V; CP_Elec_4x5.8
C4, C5, C10: 1uF; C_0805_2012Metric
C6, C7: 4.7nF; C_0805_2012Metric
D1: 1N5822/SS34/SMA; D_SMA-SMB_Universal_Handsoldering
H1, H2, H3, H4: MountingHole; MountingHole_2.7mm_M2.5
J1: Raspberry_Pi_2_3; PinSocket_2x20_P2.54mm_Vertical
J2: LEFT; PinHeader_1x01_P2.54mm_Vertical
J3: RIGHT; PinHeader_1x01_P2.54mm_Vertical
J6: 3v3; PinHeader_1x01_P2.54mm_Vertical
J7: GND; PinHeader_1x01_P2.54mm_Vertical
J8: GNDA; PinHeader_1x01_P2.54mm_Vertical
NT1, NT2: NetTie_2; SolderJumper-2_P1.3mm_Bridged_RoundedPad1.0x1.5mm
R1, R3: 100k; R_0805_2012Metric
R2: 220k; R_0805_2012Metric
U1: TCXO 49.152 MHz; Oscillator_SMD_Fordahl_DFAS11-4Pin_7.0x5.0mm_HandSoldering
U2: ES9023; SOP-16_4.4x10.4mm_P1.27mm
U5: LP5912-3.3DRV; WSON-6-1EP_2x2mm_P0.65mm_EP1x1.6mm

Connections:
+3V3: C2.1, C9.1, C10.1, J6.1, R1.2, U1.4 (VDD), U2.5 (AVCC), U5.1 (OUT)
+5V: D1.2 (A), J1.2 (5V), J1.4 (5V)
/AUDIO_LEFT: C7.1, J2.1, U2.7 (AOUTL)
/AUDIO_RIGHT: C6.1, J3.1, U2.8 (AOUTR)
/I2S_BCLK: J1.32 (PWM0/GPIO12), U2.1 (BCK)
/I2S_DOUT: J1.40 (GPIO21/SCLK1), U2.3 (SDI)
/I2S_LRCK: J1.35 (GPIO19/MISO1), U2.2 (LRCK)
/VIN: C8.1, D1.1 (K), R3.2, U5.6 (IN)
GND: C1.2, C8.2, C9.2, C10.2, J1.6 (GND), J1.9 (GND), J1.14 (GND), J1.20 (GND), J1.25 (GND), J1.30 (GND), J1.34 (GND), J1.39 (GND), J7.1, NT1.1, NT2.1, U1.2 (GND), U2.4 (DIF), U2.14 (DGND), U5.5 (GND), U5.7 (EP)
GNDA: C2.2, C3.2, C4.2, C6.2, C7.2, J8.1, NT1.2, NT2.2, R2.1, U2.12 (AGND)
unnamed: U1.3 (OUT), U2.13 (MCLK)
unnamed: C5.2, U2.10 (CN)
unnamed: C5.1, U2.9 (CP)
unnamed: C1.1, R1.1, U2.15 (MUTE_B)
unnamed: C4.1, U2.11 (NEG)
unnamed: C3.1, R2.2, U2.6 (VREG)
unnamed: R3.1, U5.4 (EN)

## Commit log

2024-07-07 This version sent to JLCPCB on 15 January 2024
    [dac-B_Cu.gbr, dac-B_Mask.gbr, dac-B_Paste.gbr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]
2024-07-07 Change footprint of EA3036 and generate gerbers + drill files
    [network_player-B_Mask.gbs, network_player-B_Paste.gbp, network_player-B_Silkscreen.gbo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]
2024-07-07 Fully update gerbers before sending again to jlcpcb, also add silkscreen with copyright
    [network_player-B_Mask.gbs, network_player-B_Paste.gbp, network_player-B_Silkscreen.gbo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]
2024-07-07 first corrections
    [network_player.kicad_pcb, network_player.kicad_sch]
2024-07-07 Modifications for v1.1
    - Remove transistors for ESP32 boot/reset and use GPIO from f1c200s
    - Connect EA3036 enable to 3.3v
    - Add RST button to tie MISO line to ground to disable booting from flash
    - Use SPI1 for ESP32 and connect SPI0 to Nand Flash and RPI connector
    [network_player-B_Mask.gbs, network_player-B_Paste.gbp, network_player-B_Silkscreen.gbo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]
2024-07-07 Add bon
    [network_player.csv]
2024-07-07 Add pos file
    [network_player-top-pos.csv, network_player-top-pos.jlcpcb.csv]
2024-07-07 Add pdf for schematics
2026-05-10 Add .gitignore for macOS, Claude, tmp/ and KiCad caches

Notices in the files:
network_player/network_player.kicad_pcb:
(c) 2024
